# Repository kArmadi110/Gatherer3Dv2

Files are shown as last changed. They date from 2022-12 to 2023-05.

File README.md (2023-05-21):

# Introduction
Raspberry Pi based 3D laser scanner.

## Example result:
Further results: ./docs/pcd_clean and ./docs/pcd_original and ./docs/results

bunny

## MARK III device:
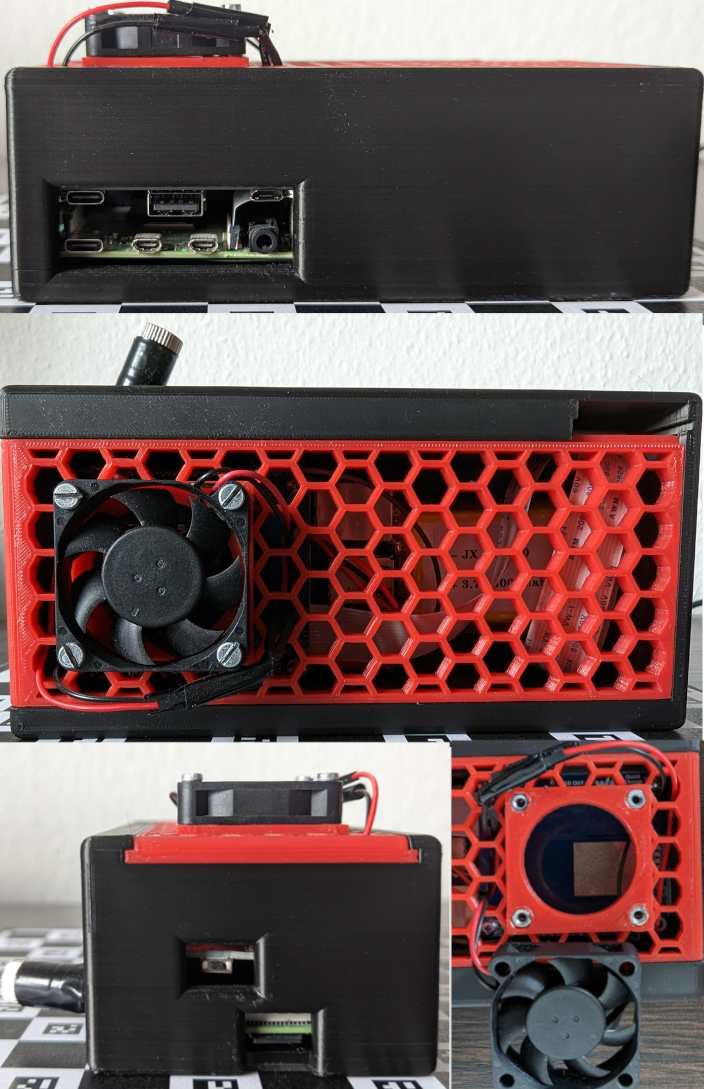
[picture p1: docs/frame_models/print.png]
bunny


# Installation

## Required models

Files to 3D print:
 - ./docs/frame_models/MARKIII-CORE.stl
 - ./docs/frame_models/MARKIII-LID.stl
 - ./docs/frame_models/MARKIII-TOP.stl

Default charuco board to print:
 - ./docs/calibration-board.png

With the proper configuration other board can be used.

## Required hardware
 - 1* Rasbperry Pi 4B 8GB (others should work but this is the one I have used)
 - 1* Raspberry Camera Module 2 with CSI cable
 - 1* 5V DC fan
 - 1* 5mW laser line projector
 - 4* M2.5 20mm screw with bolt
 - 4* M3 16mm screw with bolt 
 - Battery HAT (optional only for convinience, the device can be used with the standard power supply as well)

## Assembly
***Warning: be careful with the solder iron***

Place the CORE nuts and TOP nuts on top of the proper holes and apply heat to it. A solder iron should do the trick. Too much heat could sink the nut too deep so be careful. (check out the [bottom right corner](#mark-iii-device) )

Push the laser through the tilted hole. If it's still wobly make use a bit of tape :)
Attach the raspberry to the printed CORE with the screws.
Attach the battery HAT if you have one.
Connect the laser and camera to the device. Default laser pin is GPIO14 but this can be changed in the configs.
Put your camera in place as well and roll up the remaining cable. Push down the LID behind the camera.
Push the TOP into place and connect the fan before screwing it on top of the TOP part.
For further help check out the provided images from the [Introduction](#introduction).

## Required software

### OS and other base softwares
 - Raspberry Pi OS (64-bit) (Bullseye)
 - OpenCV with contrib (aruco and GStream) >= 4.5
### Required python packages:
 - numpy
 - open3d
 - opencv
 - autopep8
 - ffmpeg
 - picamera2
 - RPI.GPIO
### Other required software
 - rtsp-simple-server
### Software for documentation
 - radon
 - cProfile
 - snakeviz
 - plantuml
### VSCode plugins
 - The list of recommended plugins can be found in .vscode/extensions.json

## Usage
### How to run
```
python main.py
```
With Ctrl+C you can terminate the program which whill save the output to the correct file.

### Calbiration
1. Put the charuco board on a flat surface.
2. Calibrate the camera. To do this select a calbiration structure with proper settings and run the program.
3. Calibrate the laser plane. Same as the previous point except instead of Camera calibration now select a Laser calibration structure.
4. Set up your scan config structure according to the comments For further info see: ./source/core/config_constants.py and ./source/core/config_types.py.
5. And scan your object.

For further results and documentation check out ./docs/ and the code comments.

# Code analysis and Architecture

## Metrics
Source:
 - https://pypi.org/project/radon/
 - https://radon.readthedocs.io/en/latest/commandline.html

```
radon raw source -s > ./docs/raw.txt
radon cc source > ./docs/cc.txt
radon mi source > ./docs/mi.txt
python -m cProfile ./source/main.py > ./docs/analysis/cProfile.txt
python -m cProfile -o ./docs/analysis/cProfile.prof ./source/main.py
python -m snakeviz ./docs/analysis/cProfile.prof
```
Results: ./docs/analysis

## Architecture
Check out ./docs/architecture/

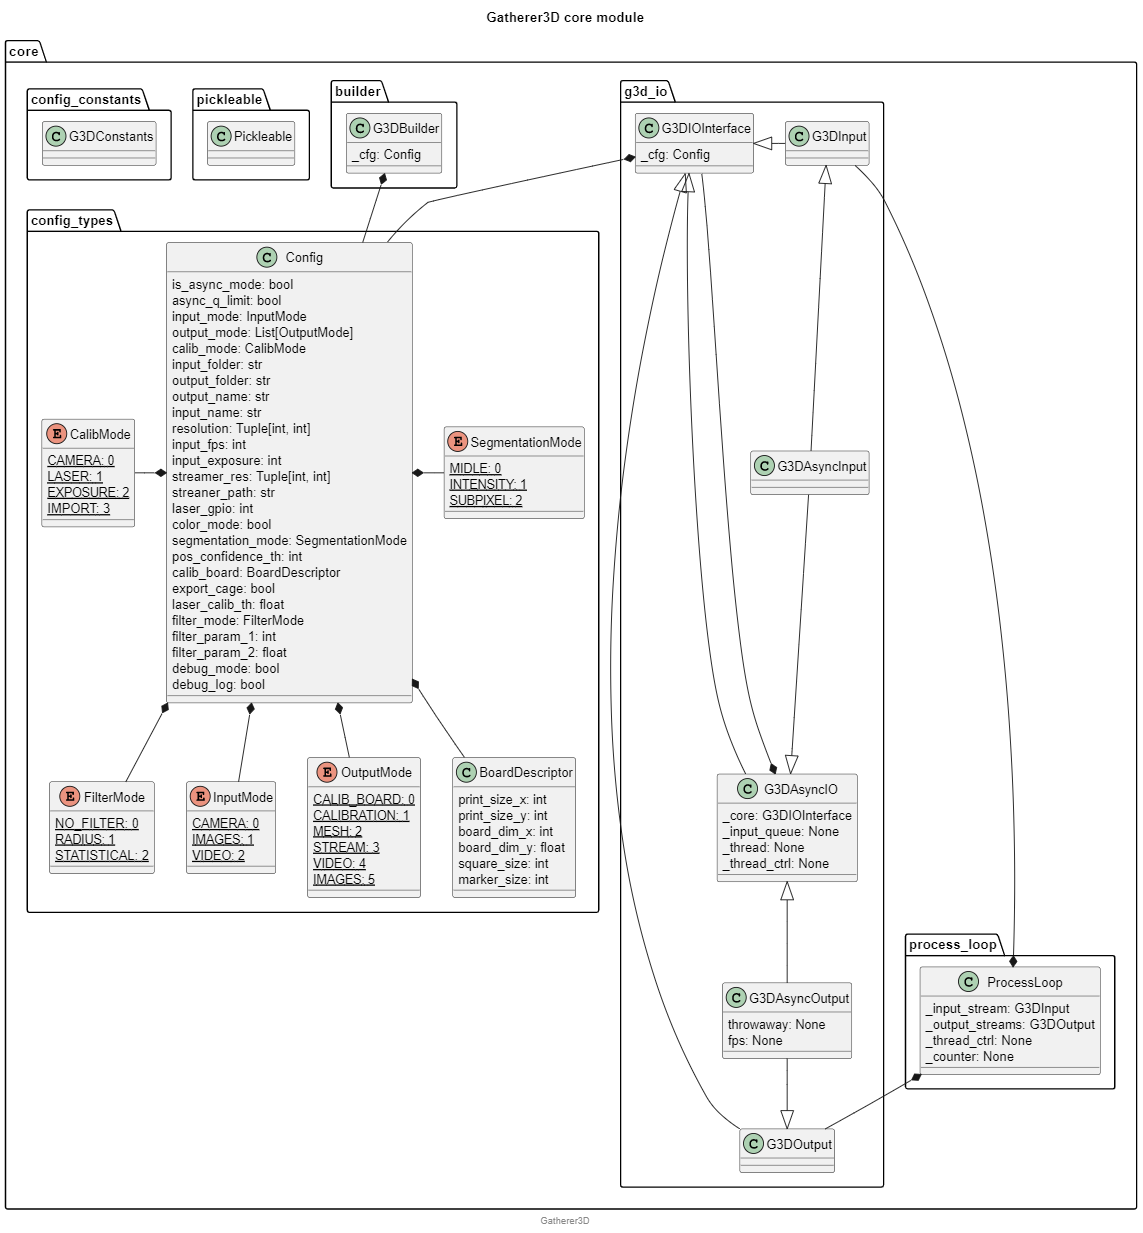
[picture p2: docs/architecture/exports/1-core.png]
core module

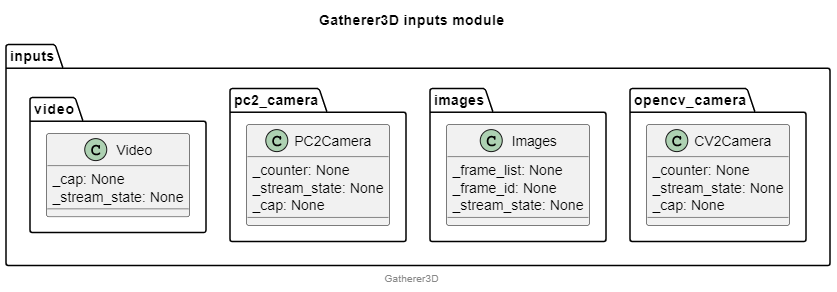
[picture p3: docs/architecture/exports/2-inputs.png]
inputs module

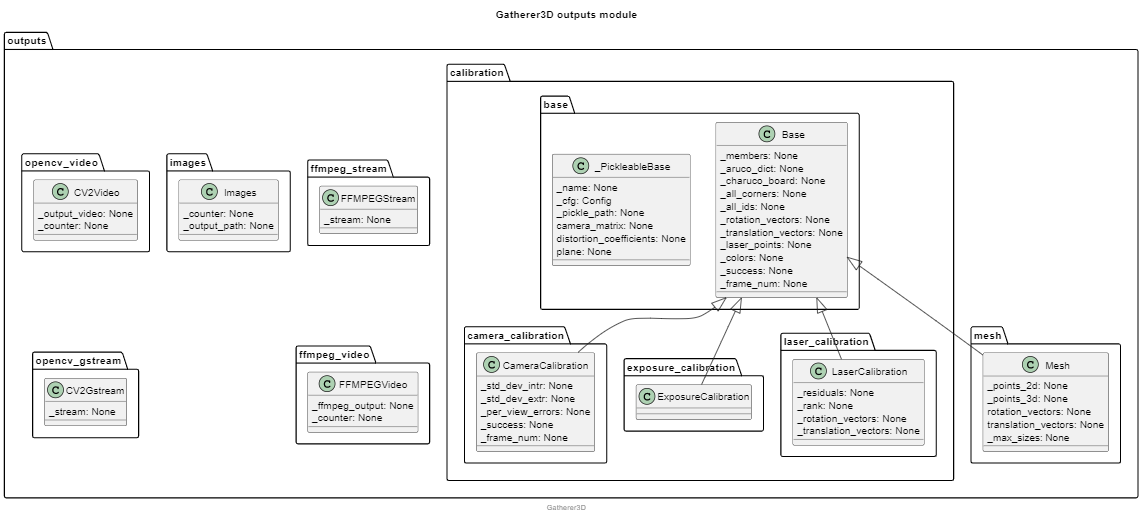
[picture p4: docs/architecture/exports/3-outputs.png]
outputs module

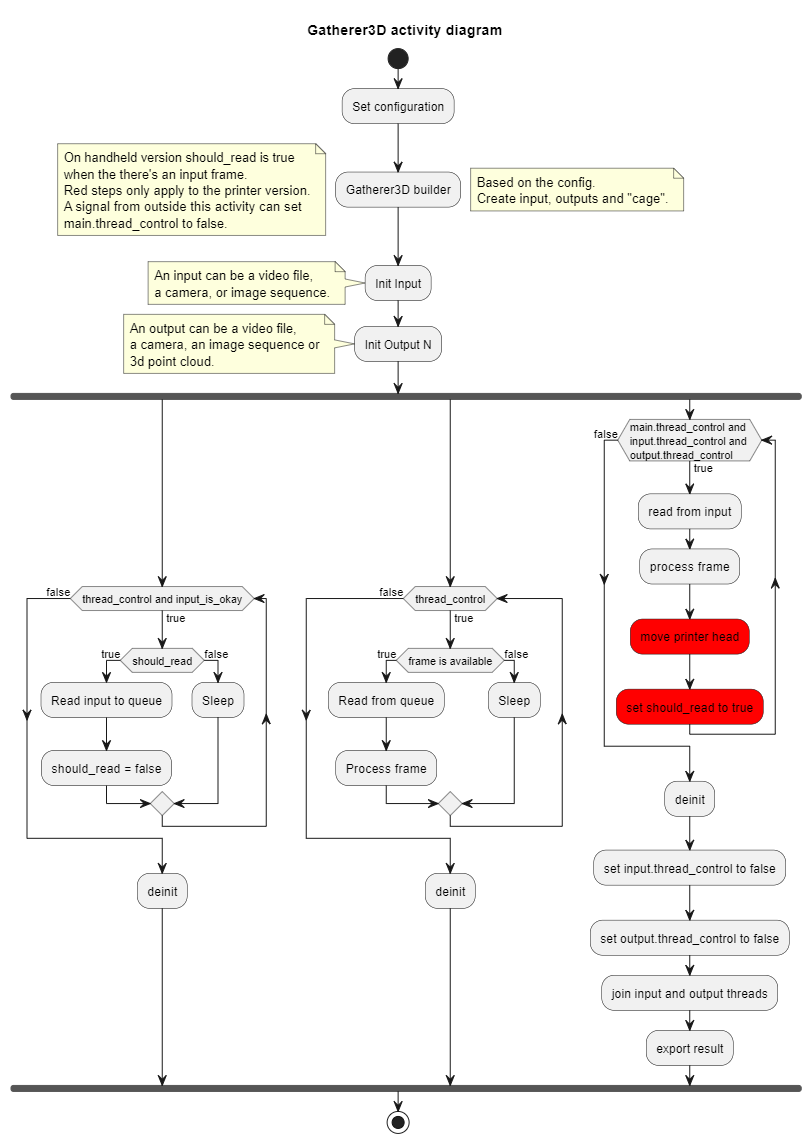
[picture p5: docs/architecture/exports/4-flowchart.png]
activity diagram

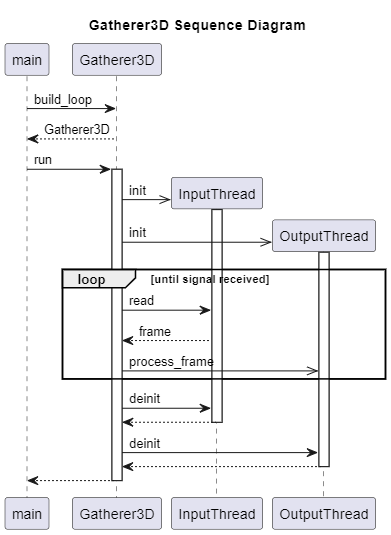
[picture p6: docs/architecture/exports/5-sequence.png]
sequence diagram


# Sources and useful links
 - https://picamera.readthedocs.io/en/release-1.13/
 - https://www.researchgate.net/publication/2401027_A_Comparison_of_Algorithms_for_Subpixel_Peak_Detection
 - https://sites.ecse.rpi.edu/~rjradke/cvfxcourse.html
 - http://mesh.brown.edu/desktop3dscan/ch4-slit.html
 - https://docs.opencv.org/4.x/da/d13/tutorial_aruco_calibration.html
 - https://docs.opencv.org/4.x/d5/dae/tutorial_aruco_detection.html
 - https://docs.opencv.org/3.4/d9/d0c/group__calib3d.html
 - https://www.thingiverse.com/thing:3731
 - https://www.thingiverse.com/thing:763622
 - https://www.thingiverse.com/thing:4066731

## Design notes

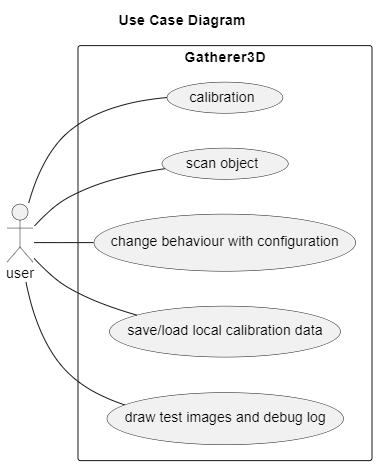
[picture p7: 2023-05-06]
docs/architecture/exports/0-use-case.png

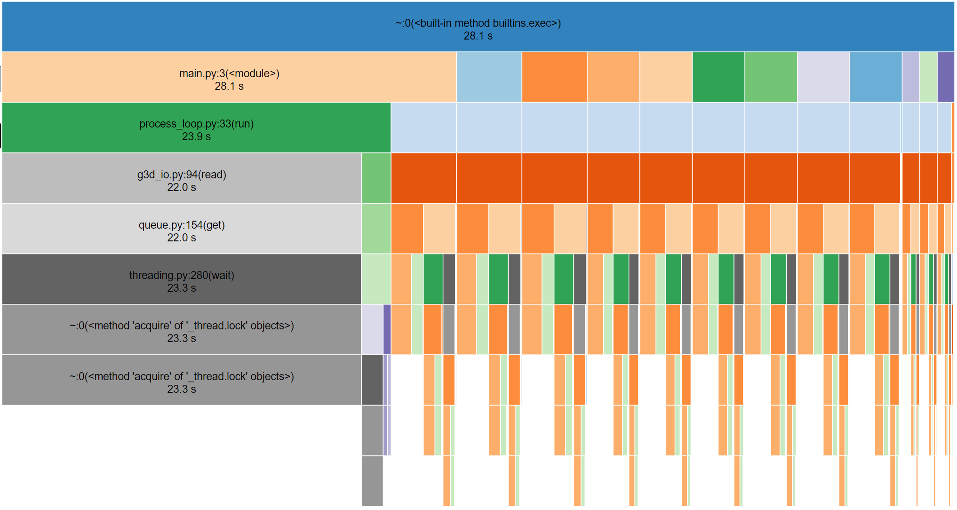
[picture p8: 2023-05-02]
docs/analysis/runtime_main.png

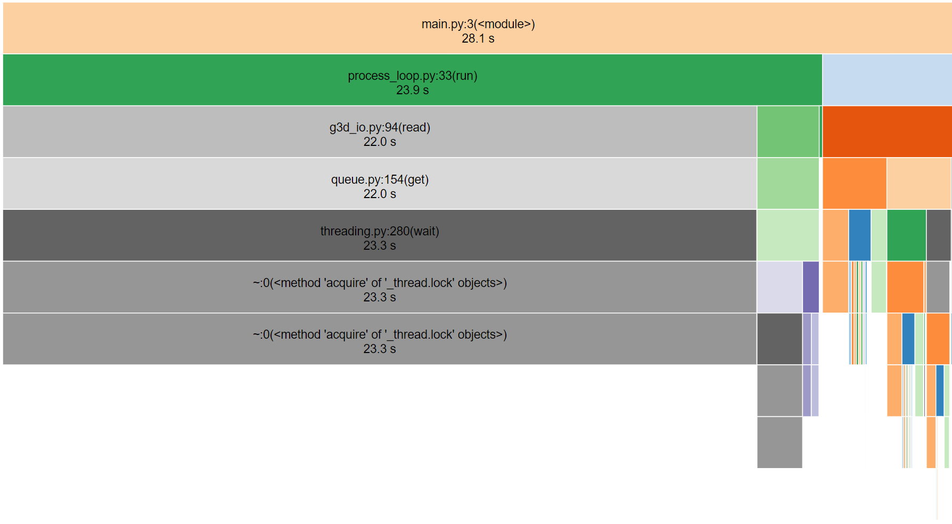
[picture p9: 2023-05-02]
docs/analysis/runtime_root.png

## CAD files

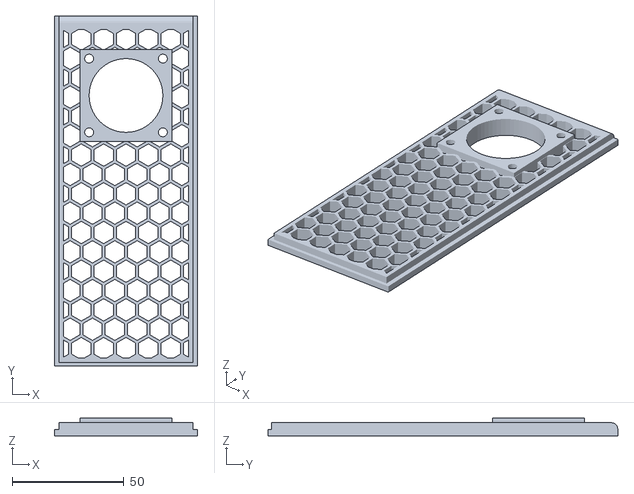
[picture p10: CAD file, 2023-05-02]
docs/frame_models/MARK-III-TOP.stl
64.0 x 156.5 x 7.90

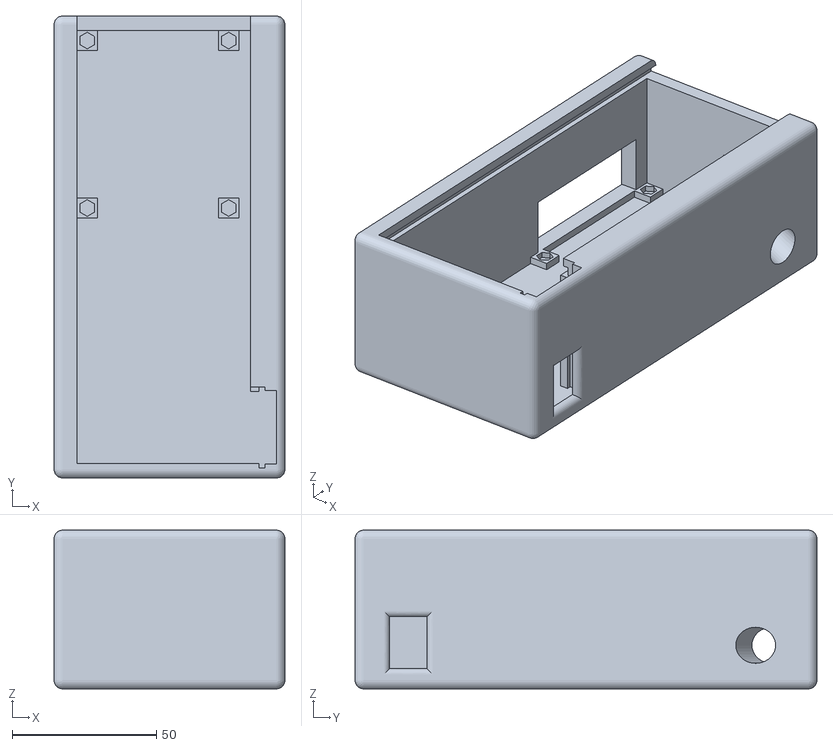
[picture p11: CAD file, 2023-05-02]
docs/frame_models/MARK-III-CORE.stl
80.0 x 160.0 x 55.0

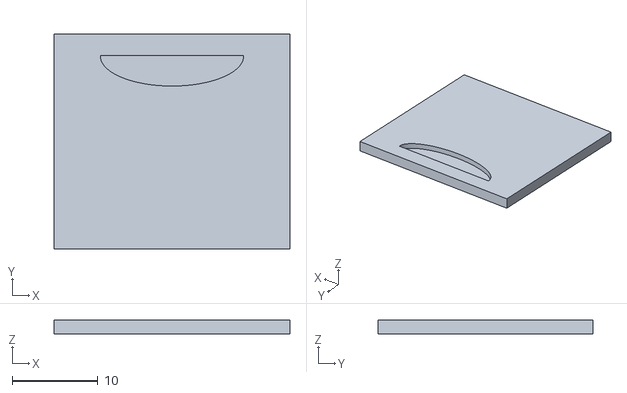
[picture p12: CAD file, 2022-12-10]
docs/frame_models/MARK-III-LID.stl
27.5 x 25.0 x 1.60

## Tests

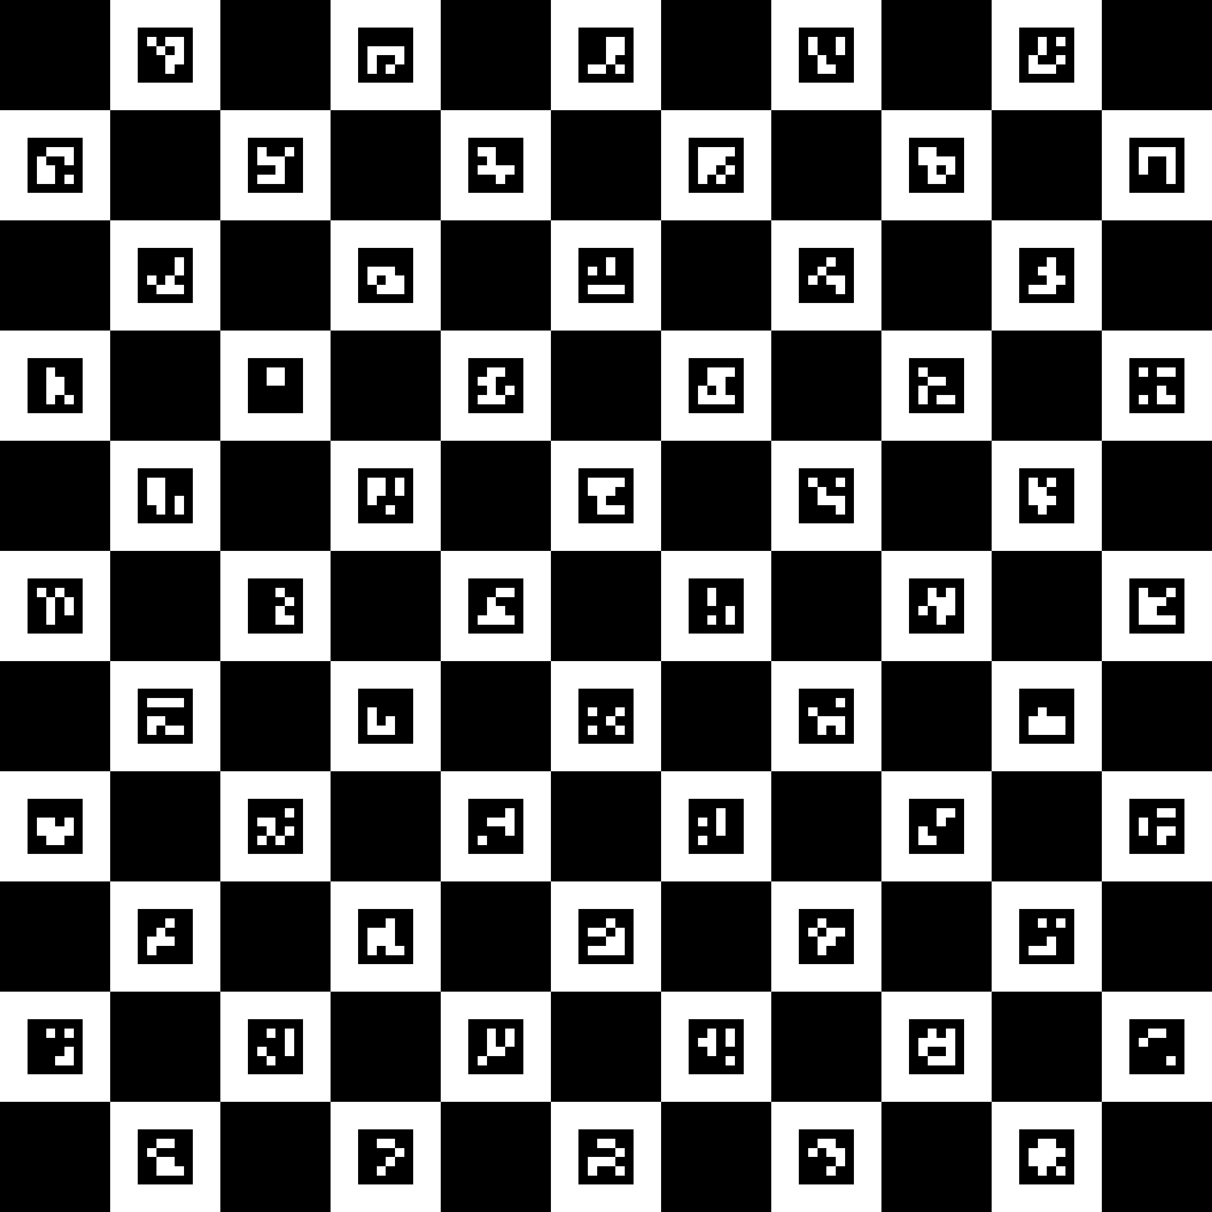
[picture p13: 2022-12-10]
docs/calibration-board.png

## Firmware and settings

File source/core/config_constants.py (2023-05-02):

from core.config_types import Config, InputMode, OutputMode, CalibMode, SegmentationMode, FilterMode


class G3DConstants:
    """Constants for the G3D system.
    With example configurations
    """

    recording_config = Config(
        is_async_mode=True,
        async_q_limit=5,

        input_mode=InputMode.CAMERA,
        output_mode=[OutputMode.VIDEO],
        calib_mode=CalibMode.IMPORT,

        input_folder="./bin/calib1/",
        output_folder="./bin/calib1/images/",
        output_name="calib1",
        input_name="calib1.mp4",

        resolution=(1640, 1232),
        # resolution=(1280, 720),
        input_fps=10,
        input_exposure=100,

        streamer_res=(640, 480),
        streaner_path="rtsp://localhost:8554/G3D",

        laser_gpio=14,
        color_mode=False,
        segmentation_mode=SegmentationMode.SUBPIXEL,
        pos_confidence_th=0.1
    )

    scan_config1 = Config(
        is_async_mode=True,
        async_q_limit=5,

        input_mode=InputMode.CAMERA,
        output_mode=[OutputMode.MESH, OutputMode.STREAM],
        calib_mode=CalibMode.IMPORT,

        input_folder="./bin/",
        output_folder="./bin/",
        output_name="YODA",
        input_name="/dev/video0",

        resolution=(1640, 1232),
        input_fps=15,
        input_exposure=100000,

        streamer_res=(640, 480),
        streaner_path="rtsp://localhost:8554/G3D",

        laser_gpio=14,
        color_mode=False,
        segmentation_mode=SegmentationMode.SUBPIXEL,
        pos_confidence_th=0.1
    )

    calib_config1 = Config(
        is_async_mode=False,
        async_q_limit=5,

        input_mode=InputMode.VIDEO,
        output_mode=[OutputMode.CALIBRATION],
        calib_mode=CalibMode.CAMERA,

        input_folder="./bin/calib2/",
        output_folder="./bin/calib2/",
        # output_folder="./bin/calib2/intensity",
        # output_folder="./bin/calib1/subpixel",
        # output_folder="./bin/calib1/middle",
        output_name="calib_report",
        input_name="calib2.mp4",

        resolution=(1640, 1232),
        input_fps=15,
        input_exposure=100,

        streamer_res=(640, 480),
        streaner_path="rtsp://localhost:8554/G3D",

        laser_gpio=14,
        color_mode=False,
        segmentation_mode=SegmentationMode.INTENSITY,
        pos_confidence_th=0.1
    )

    calib_config2 = Config(
        is_async_mode=True,
        async_q_limit=5,

        input_mode=InputMode.CAMERA,
        output_mode=[OutputMode.CALIBRATION],  # OutputMode.STREAM
        calib_mode=CalibMode.LASER,

        input_folder="./bin/",
        output_folder="./bin/calib1",
        output_name="test1",
        input_name="test1",

        resolution=(1640, 1232),
        input_fps=30,
        input_exposure=10000,

        streamer_res=(640, 480),
        streaner_path="rtsp://localhost:8554/G3D",

        laser_gpio=14,
        # laser_gpio=0,
        color_mode=False,
        segmentation_mode=SegmentationMode.SUBPIXEL,
        pos_confidence_th=0.5,

        # filter_mode=FilterMode.RADIUS,
        # filter_param_1=20,
        # filter_param_2=0.001

        filter_mode=FilterMode.STATISTICAL,
        filter_param_1=10,
        filter_param_2=2.0
    )

    scan_config2 = Config(
        is_async_mode=True,
        async_q_limit=5,

        input_mode=InputMode.CAMERA,
        # output_mode=[OutputMode.MESH, OutputMode.STREAM],
        output_mode=[OutputMode.MESH],
        calib_mode=CalibMode.NONE,

        input_folder="./bin/",
        output_folder="./docs/pcd_original/",
        output_name="xcube",
        input_name="test1",

        resolution=(1640, 1232),
        input_fps=30,
        input_exposure=10000,

        streamer_res=(640, 480),
        streaner_path="rtsp://localhost:8554/G3D",

        laser_gpio=14,
        color_mode=False,
        segmentation_mode=SegmentationMode.SUBPIXEL,
        pos_confidence_th=0.2,
        export_cage=True,

        filter_mode=FilterMode.STATISTICAL,
        filter_param_1=10,
        filter_param_2=2.0
    )

    main_config = None

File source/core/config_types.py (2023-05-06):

from enum import Enum
from dataclasses import dataclass
from typing import List
from typing import Tuple


class InputMode(Enum):
    CAMERA = 0
    IMAGES = 1
    VIDEO = 2


class OutputMode(Enum):
    CALIB_BOARD = 0
    CALIBRATION = 1
    MESH = 2
    STREAM = 3
    VIDEO = 4
    IMAGES = 5


class CalibMode(Enum):
    CAMERA = 0
    LASER = 1
    EXPOSURE = 2
    IMPORT = 3
    NONE = 3


class SegmentationMode(Enum):
    MIDLE = 0
    INTENSITY = 1
    SUBPIXEL = 2


class FilterMode(Enum):
    NO_FILTER = 0
    RADIUS = 1
    STATISTICAL = 2


@dataclass
class BoardDescriptor():
    print_size_x: int = 2200
    print_size_y: int = 2200
    board_dim_x: int = 11
    board_dim_y: float = 11
    square_size: int = 0.02
    marker_size: int = 0.01


@dataclass
class Config():
    """Main configuration class"""

    # determines is async mode is used (True for multithreading)
    is_async_mode: bool
    # determines the maximum size of the async queue
    async_q_limit: bool

    # input mode (camera, images, video)
    input_mode: InputMode
    # output mode (calibration, mesh, stream)
    output_mode: List[OutputMode]
    # calibration mode (camera, laser, exposure, import). Only used if CALIBRATION is in output_mode
    calib_mode: CalibMode

    # input and output folders and names
    input_folder: str
    output_folder: str
    output_name: str
    input_name: str

    resolution: Tuple[int, int]
    input_fps: int
    input_exposure: int

    # streamer resolution and path. Only used if STREAM is in output_mode
    streamer_res: Tuple[int, int]
    streaner_path: str

    laser_gpio: int
    # experimental color mdoe
    color_mode: bool
    segmentation_mode: SegmentationMode

    # confidence threshold percentage for position detection
    pos_confidence_th: int
    # calibration board descriptor
    calib_board: BoardDescriptor = BoardDescriptor()

    # True if only the calib_board size cage should be exported
    export_cage: bool = True

    # laser threshold for segmentation
    # laser_calib_th *width*height is the number of pixels that should be allowed
    # above that we have a faulty segmentation
    laser_calib_th: float = 0.02

    # filter mode and parameters for outlier filtering for the mesh
    filter_mode: FilterMode = FilterMode.NO_FILTER
    filter_param_1: int = 0
    filter_param_2: float = 0

    debug_mode: bool = False
    debug_log: bool = True

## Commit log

2022-12-10 async output + calibration base refactor + new README
    [MARK-III-CORE.stl, MARK-III-LID.stl, MARK-III-TOP.stl]
2022-12-11 calibration fixes part1
2023-05-02 a couple of fix and example
    [MARK-III-CORE.stl, MARK-III-LID.stl, MARK-III-TOP.stl]
2023-05-21 Figure switch
